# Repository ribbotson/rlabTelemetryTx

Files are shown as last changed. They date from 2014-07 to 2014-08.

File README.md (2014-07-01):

rlabTelemetryTx
===============

rlab Telemetry Transmitter

This repository contains code, hardware information and data relating to the rlab Telemetry Transmittter.

The rlab Telemetry Transmitter is an ATXMega128A4U based development board for High altitude Balloon tracking and telemetry.
The transmitter is a Radiometrix NTX2B 434MHz module and the GPS is the Ublox7q. The board is programmed using Atmel DFU over the
USB .

Software is based around the Atmel Software Framework ASF.

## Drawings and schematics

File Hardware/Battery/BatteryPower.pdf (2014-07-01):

A

A

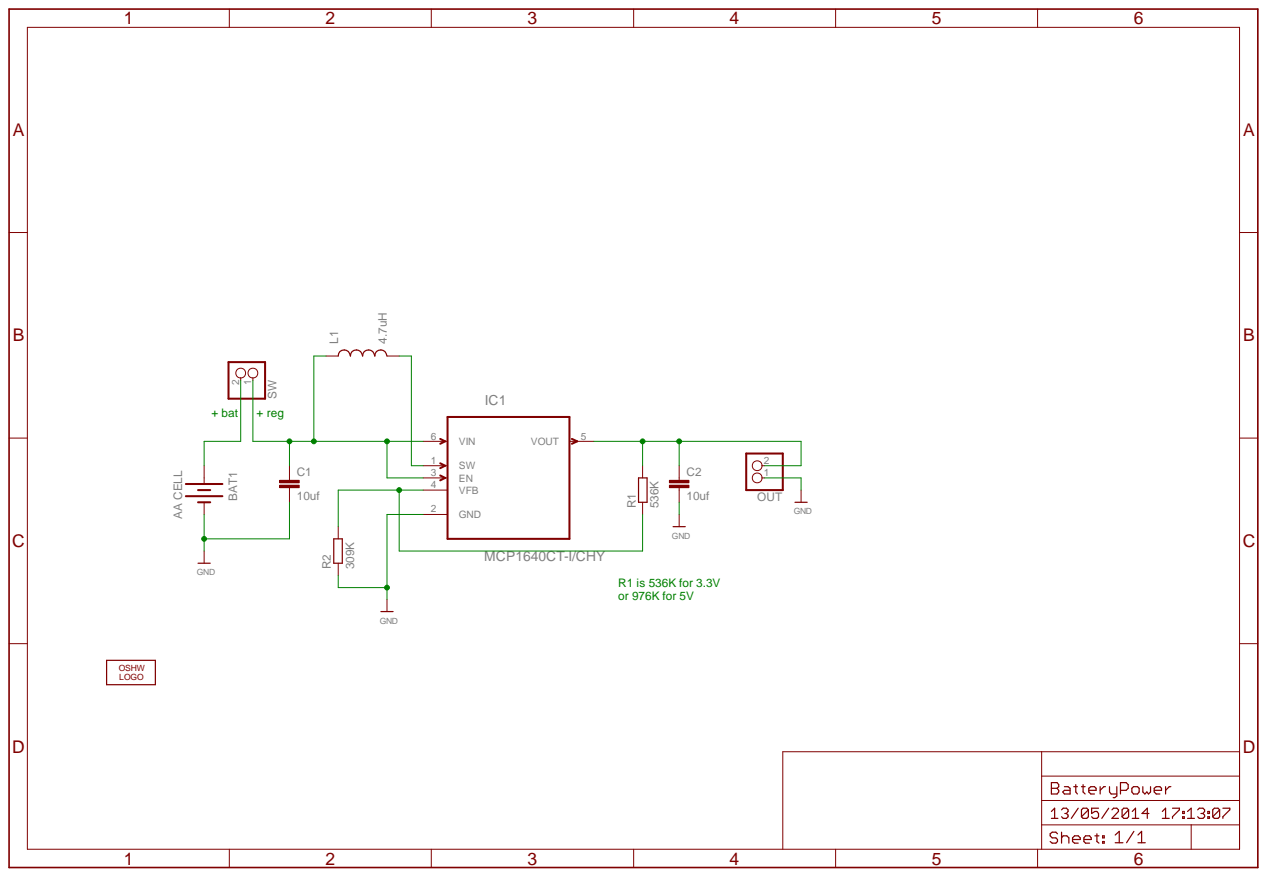
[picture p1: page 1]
AA CELL; GND; MCP1640CT-I/CHY; 4.7uH GND; BAT1; VIN 6; SW 1 EN 3 VFB 4; GND 2; VOUT; OUT; OSHW LOGO; + bat; + reg; R1 is 536K for 3.3V or 976K for 5V

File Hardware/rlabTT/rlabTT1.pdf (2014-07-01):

IC4

A

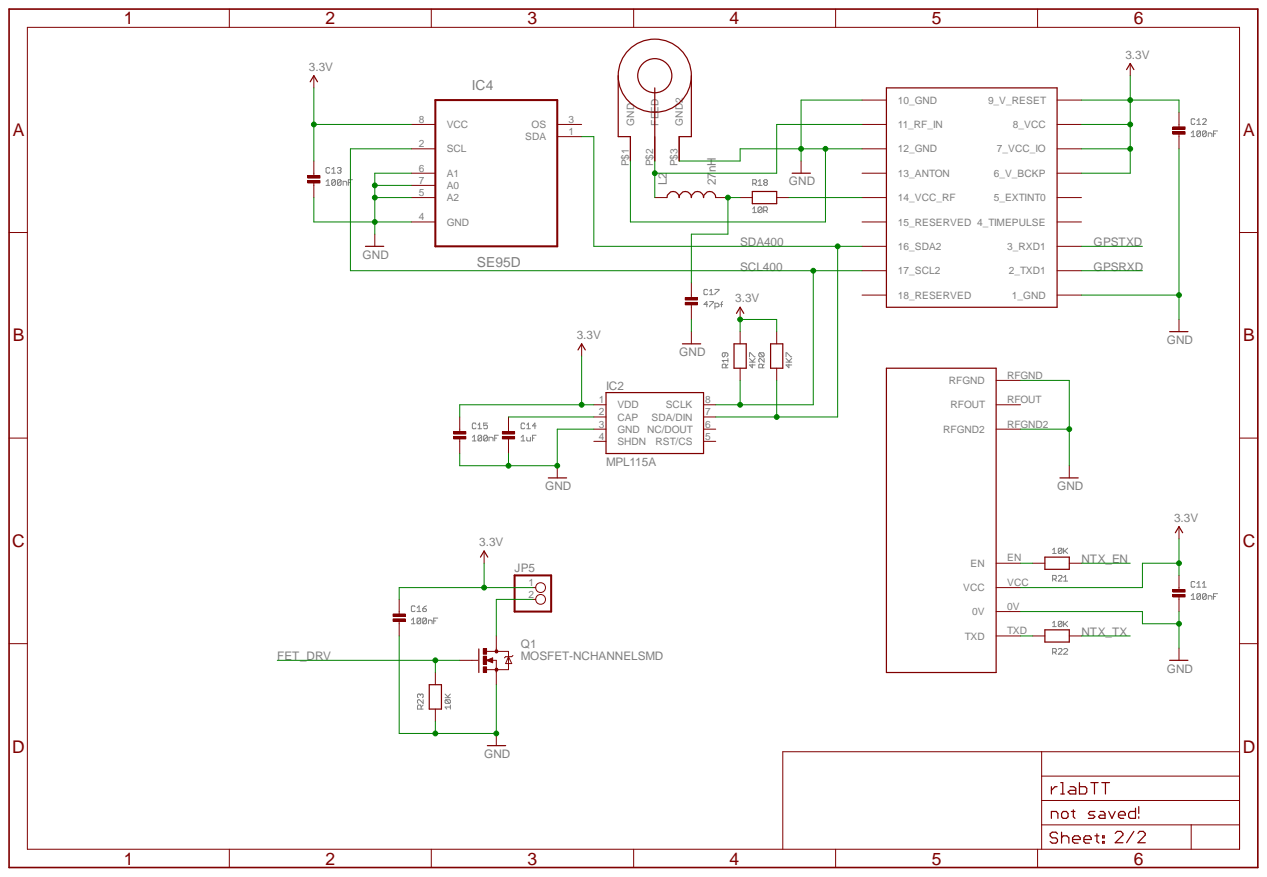
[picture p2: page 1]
GND; MPL115A; MOSFET-NCHANNELSMD; 10_GND; 12_GND; 13_ANTON; 14_VCC_RF; 15_RESERVED; 16_SDA2; 17_SCL2; 18_RESERVED; 9_V_RESET; 8_VCC; 7_VCC_IO; 6_V_BCKP; 5_EXTINT0; 4_TIMEPULSE; 3_RXD1; 2_TXD1; 1_GND; RFGND; RFOUT; VCC; TXD; RFGND2; IC2 VDD 1 CAP 2 GND 3; SHDN 4; RST/CS; 5 NC/DOUT; 6 SDA/DIN; 7 SCLK; FEED P$2; GND P$1; GND2 P$3; VCC 8; SCL 2; GND 4; SDA; GPSRXD; GPSTXD; SCL400; SDA400; FET_DRV; NTX_EN; NTX_TX

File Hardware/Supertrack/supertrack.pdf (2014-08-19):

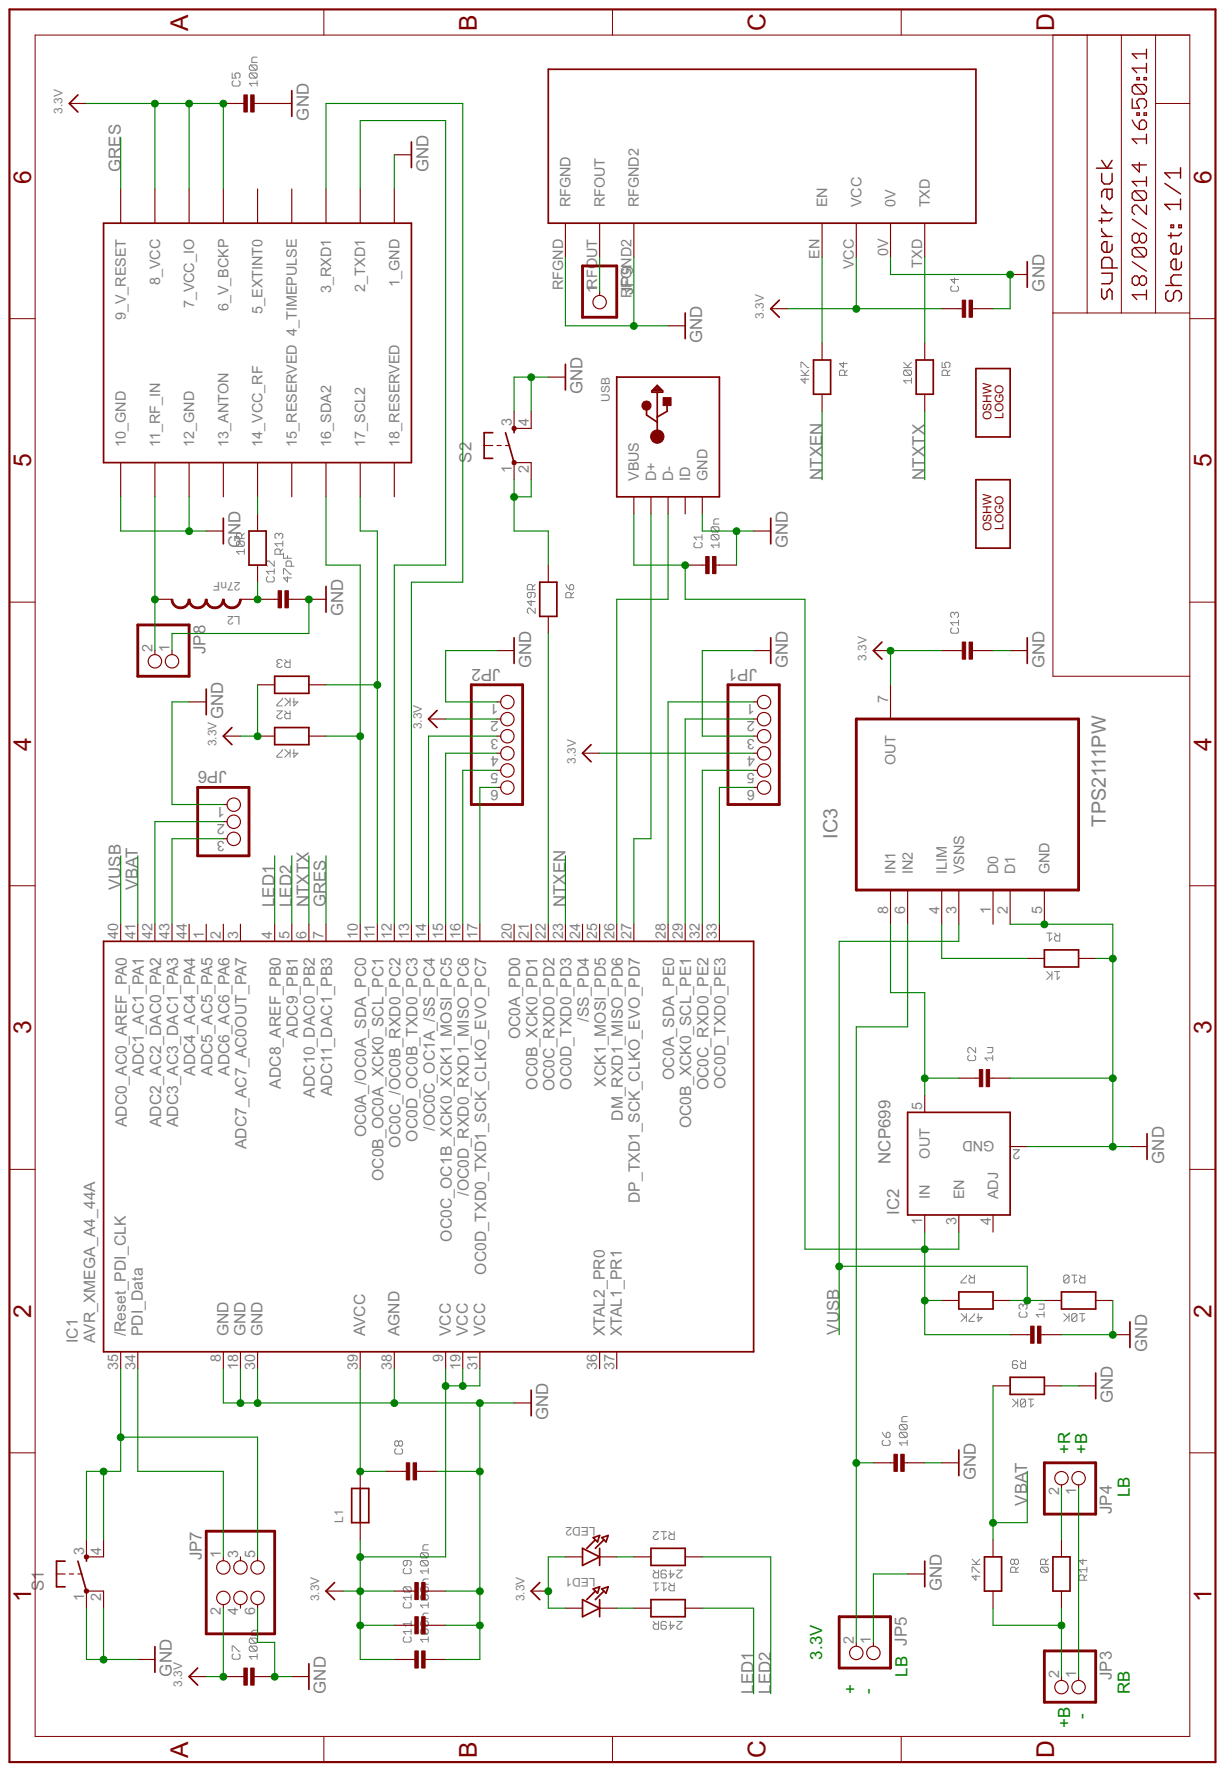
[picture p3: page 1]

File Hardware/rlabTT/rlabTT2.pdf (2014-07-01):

A

A

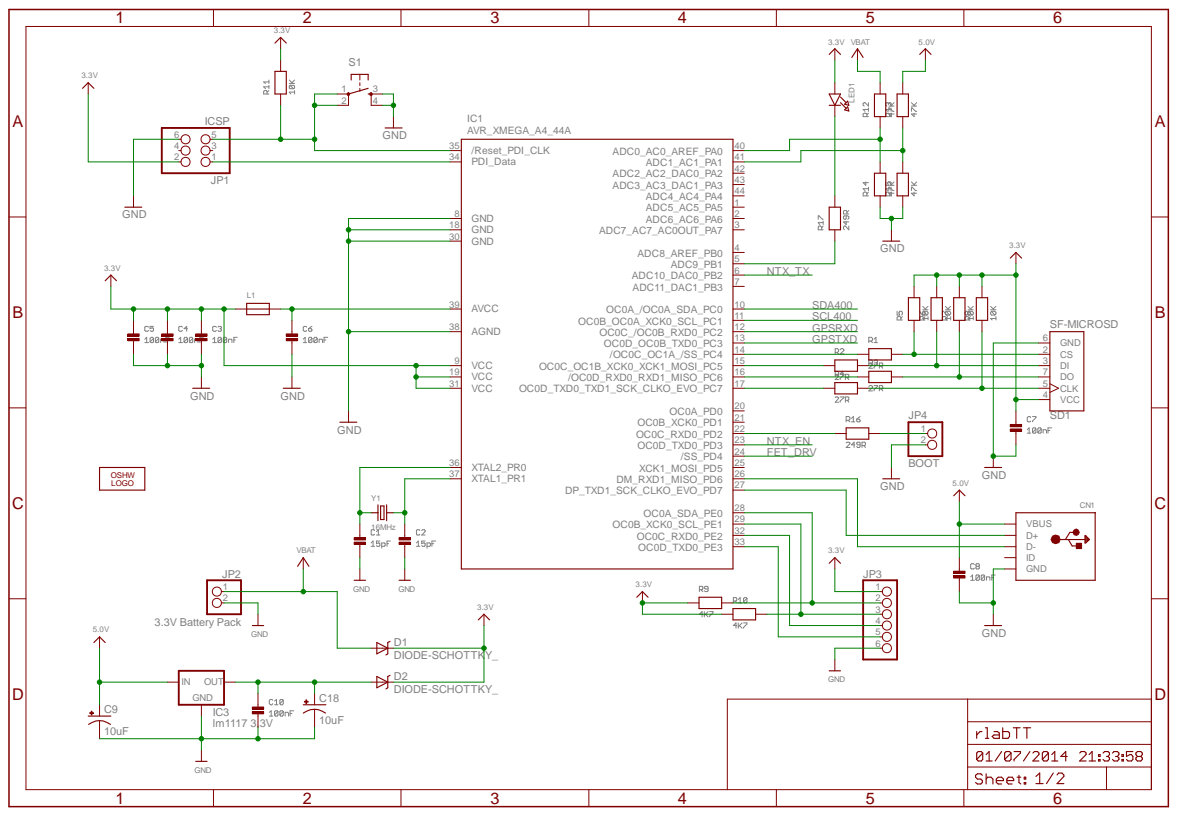
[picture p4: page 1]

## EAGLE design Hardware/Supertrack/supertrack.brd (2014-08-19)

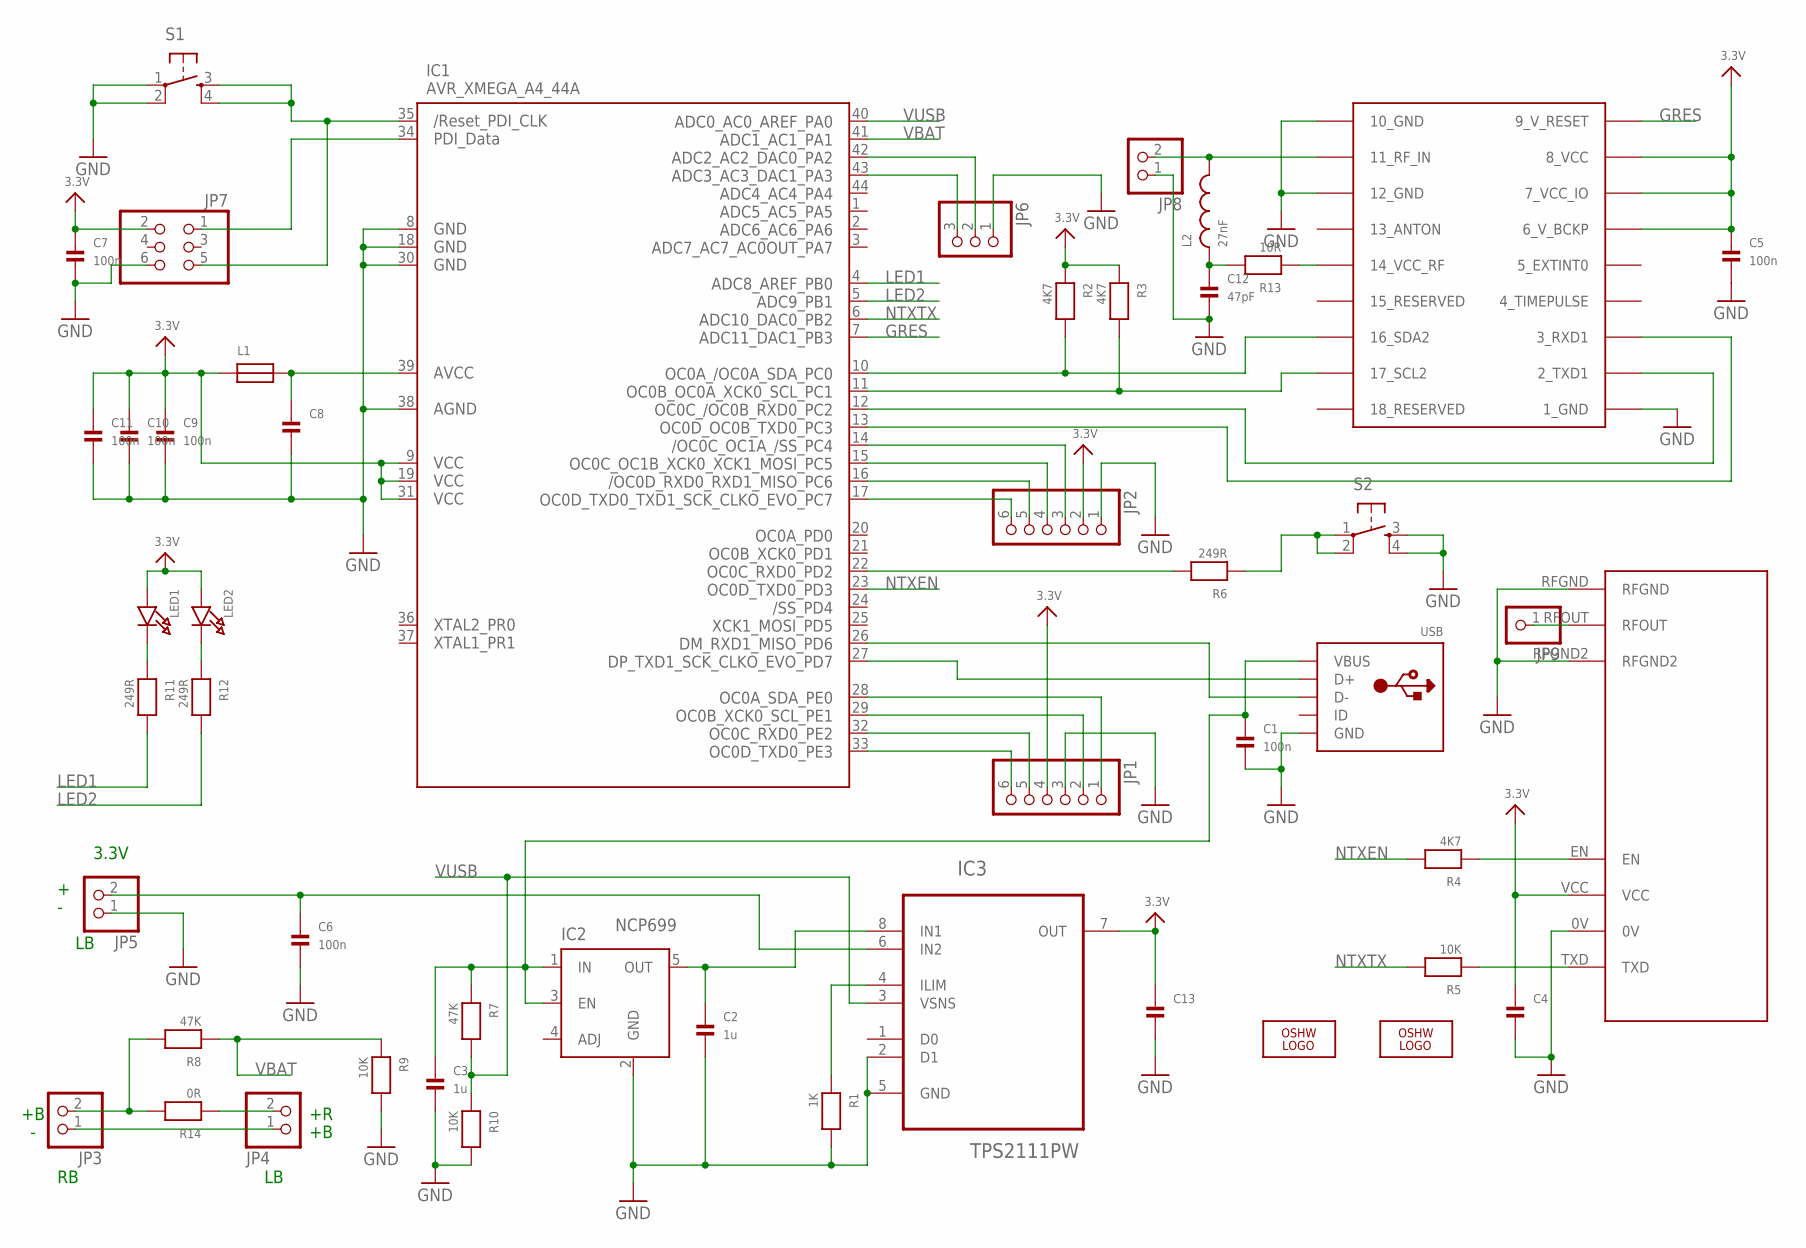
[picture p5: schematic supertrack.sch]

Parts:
C1, C5, C6, C7, C9, C10, C11: 100n; 0603
C2, C3: 1u; 0603
C4, C8, C13: CAP_CERAMIC0603; 0603
C12: 47pF; 0603
IC1: AVR_XMEGA_A4_44A; TQFP44
IC2: NCP699; SOT23-5
IC3: TPS2111PW; SOP65P640X120-8N
JP1, JP2: PINHD-1X6; 1X06
JP3, JP4, JP5: PINHD-1X2; 1X02
JP6: PINHD-1X3; 1X03
JP7: PINHD-2X3; 2X03
JP8: HEADER-1X2ROUND; 1X02_ROUND
JP9: HEADER-1X1ROUND; 1X01_ROUND
L1: FERRITE; 0603
L2: 27nF; 0603
LED1, LED2: LED0603; CHIPLED_0603
LOGO1: OSHW_LOGO_8MILX0150-NT; OSHW_8X150_NOTEXT
LOGO2: OSHW_LOGO_8MILX0100-NT; OSHW_8X100_NOTEXT
R1: 1K; 0603
R2, R3, R4: 4K7; 0603
R5, R9, R10: 10K; 0603
R6, R11, R12: 249R; 0603
R7, R8: 47K; 0603
R13: 10R; 0603
R14: 0R; 0603
S1, S2: TAC_SWITCHSMD; TACTILE_SWITCH_SMD
U$1: NTX2
U$2: UBLOX_MAX
USB: USBMINIB; USB-MINIB

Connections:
3.3V: C4.1, C5.1, C7.1, C9.1, C10.1, C11.1, C13.1, IC1.9 (VCC1), IC1.19 (VCC2), IC1.31 (VCC3), IC3.7 (OUT), JP1.4, JP2.2, JP7.2, L1.1, LED1.A, LED2.A, R2.1, R3.1, U$1.VCC, U$2.6_V_BCKP, U$2.7_VCC_IO, U$2.8_VCC
GND: C1.2, C2.2, C3.2, C4.2, C5.2, C6.2, C7.2, C8.2, C9.2, C10.2, C11.2, C12.2, C13.2, IC1.8 (GND1), IC1.18 (GND2), IC1.30 (GND3), IC1.38 (AGND), IC2.2 (GND), IC3.2 (D1), IC3.5 (GND), JP1.3, JP2.1, JP5.1, JP6.1, JP7.6, JP8.1, R1.2, R9.2, R10.2, S1.1, S1.2, S2.3, S2.4, U$1.0V, U$1.RFGND, U$1.RFGND2, U$2.1_GND, U$2.10_GND, U$2.12_GND, USB.GND
GRES: IC1.7 (PB3), U$2.9_V_RESET
LED1: IC1.4 (PB0), R11.2
LED2: IC1.5 (PB1), R12.2
unnamed: C2.1, IC2.5 (OUT), IC3.8 (IN1)
unnamed: IC1.33 (PE3), JP1.6
unnamed: IC1.32 (PE2), JP1.5
unnamed: C6.1, IC3.6 (IN2), JP5.2
unnamed: R6.1, S2.1, S2.2
unnamed: IC1.26 (PD6), USB.D-
unnamed: IC1.27 (PD7), USB.D+
unnamed: IC1.22 (PD2), R6.2
unnamed: R5.1, U$1.TXD
unnamed: R4.1, U$1.EN
unnamed: JP9.1, U$1.RFOUT
unnamed: C1.1, C3.1, IC2.1 (IN), IC2.3 (EN), R7.1, USB.VBUS
unnamed: IC3.4 (ILIM), R1.1
unnamed: IC1.10 (PC0), R2.2, U$2.16_SDA2
unnamed: IC1.11 (PC1), R3.2, U$2.17_SCL2
unnamed: IC1.12 (PC2), U$2.2_TXD1
unnamed: IC1.13 (PC3), U$2.3_RXD1
unnamed: LED2.C, R12.1
unnamed: LED1.C, R11.1
unnamed: IC1.29 (PE1), JP1.2
unnamed: IC1.28 (PE0), JP1.1
unnamed: IC1.17 (PC7), JP2.6
unnamed: IC1.16 (PC6), JP2.5
unnamed: IC1.15 (PC5), JP2.4
unnamed: IC1.14 (PC4), JP2.3
unnamed: JP3.1, JP4.1
unnamed: JP4.2, R14.1
unnamed: IC1.34 (PDI_DATA), JP7.1
unnamed: IC1.35 (RESET), JP7.5, S1.3, S1.4
unnamed: IC1.42 (PA2), JP6.2
unnamed: IC1.43 (PA3), JP6.3
unnamed: JP8.2, L2.2, U$2.11_RF_IN
unnamed: C12.1, L2.1, R13.2
unnamed: R13.1, U$2.14_VCC_RF
unnamed: C8.1, IC1.39 (AVCC), L1.2
NTXEN: IC1.23 (PD3), R4.2
NTXTX: IC1.6 (PB2), R5.2
VBAT: IC1.41 (PA1), R8.1, R9.1
VIN: JP3.2, R8.2, R14.2
VUSB: IC1.40 (PA0), IC3.3 (VSNS), R7.2, R10.1

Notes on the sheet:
3.3V

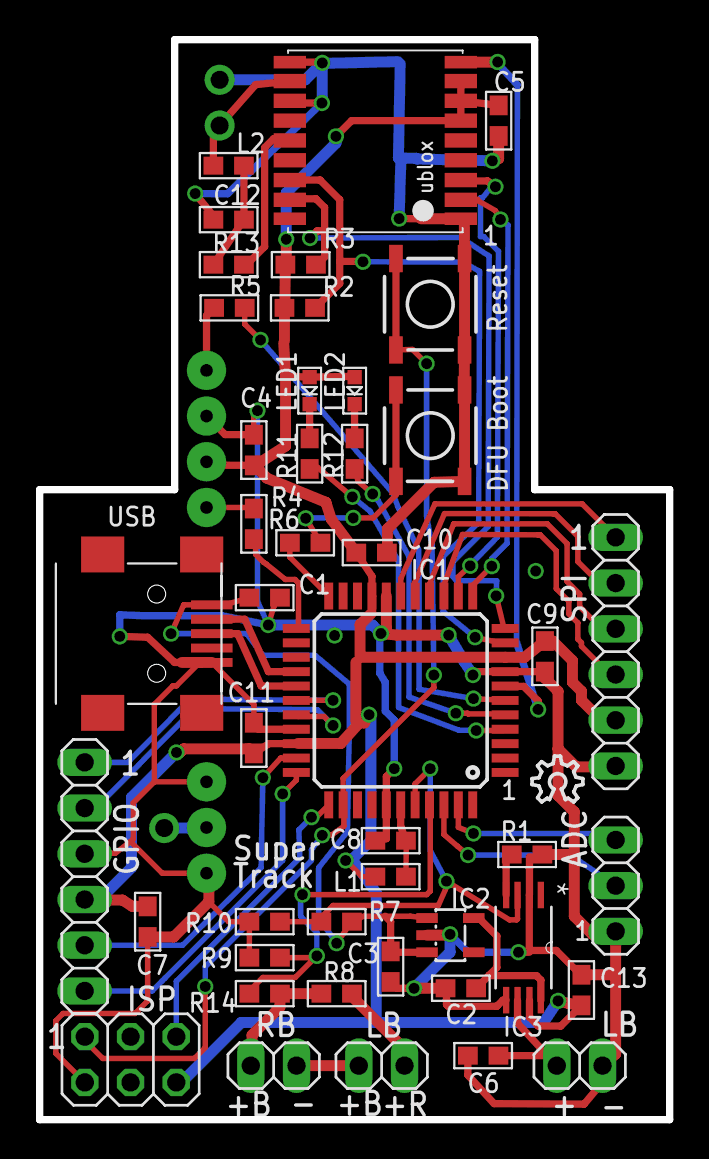
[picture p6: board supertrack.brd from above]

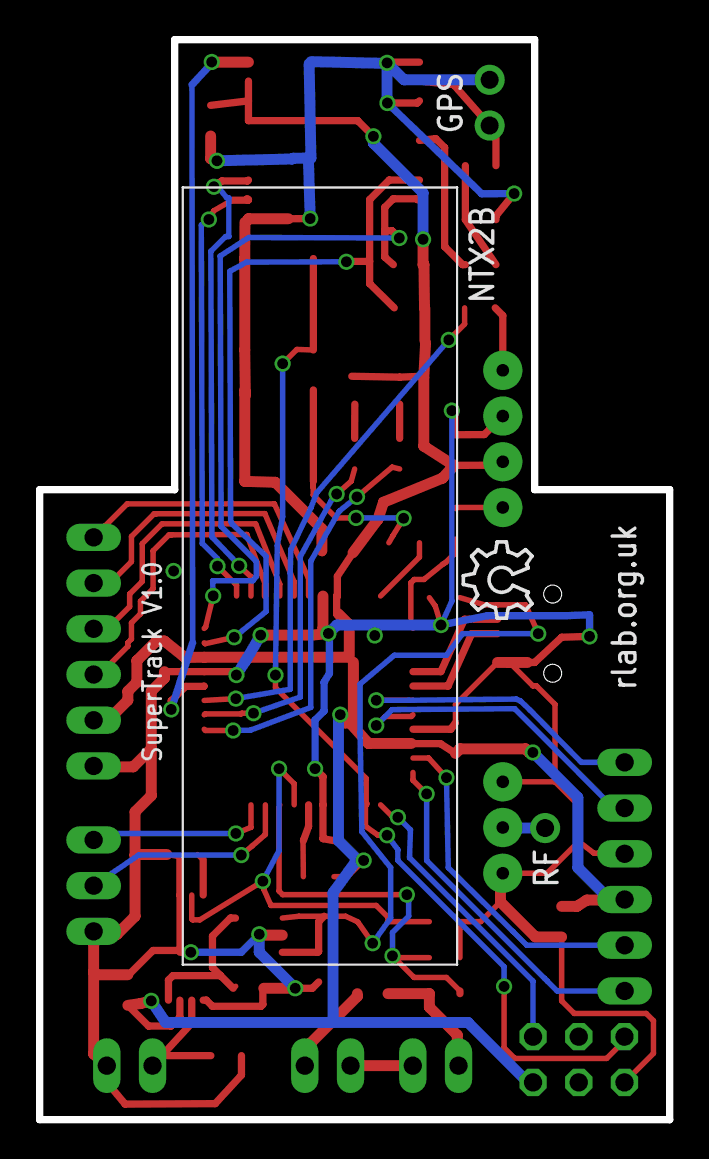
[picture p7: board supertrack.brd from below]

Board: 2 copper layers, 35.0 x 60.0 mm, 50 parts (2 on the bottom side), 45 nets.

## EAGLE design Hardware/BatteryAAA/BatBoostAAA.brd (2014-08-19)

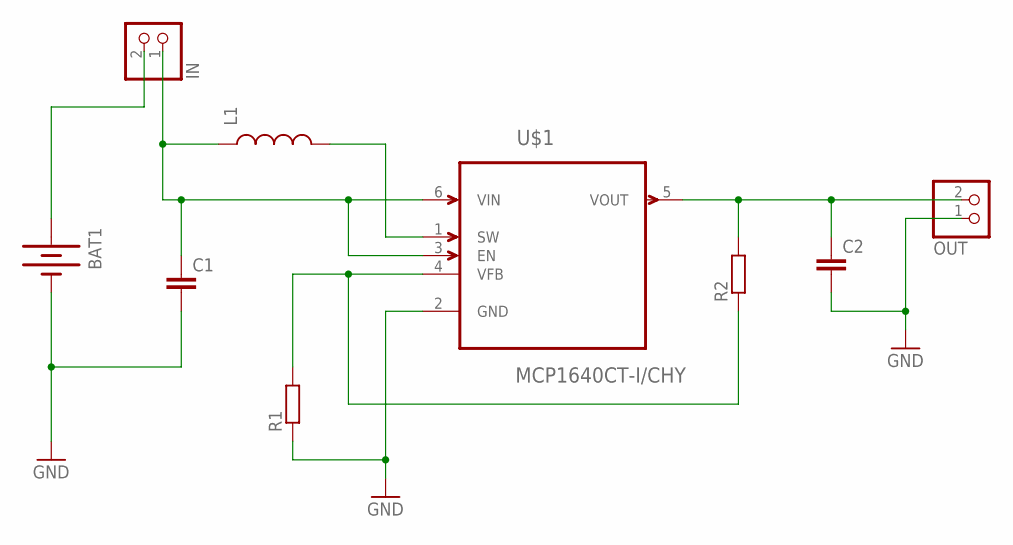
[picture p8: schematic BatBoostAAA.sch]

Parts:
BAT1: BATTERYAAA; BATTERY-AAA
C1, C2: C-EUC0805K; C0805K
IN: PINHD-1X2; 1X02
L1: INDUCTOR1210; LQH32
OUT: PINHD-1X2; 1X02
R1, R2: R-EU_R0603; R0603
U$1: MCP1640CT-I/CHY; SOT95P270X145-6N

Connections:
GND: BAT1.GND@1 (-), C1.2, C2.2, OUT.1, R1.1, U$1.2 (GND)
unnamed: C1.1, IN.1, L1.1, U$1.3 (EN), U$1.6 (VIN)
unnamed: C2.1, OUT.2, R2.2, U$1.5 (VOUT)
unnamed: R1.2, R2.1, U$1.4 (VFB)
unnamed: L1.2, U$1.1 (SW)
unnamed: BAT1.PWR@1 (+), IN.2

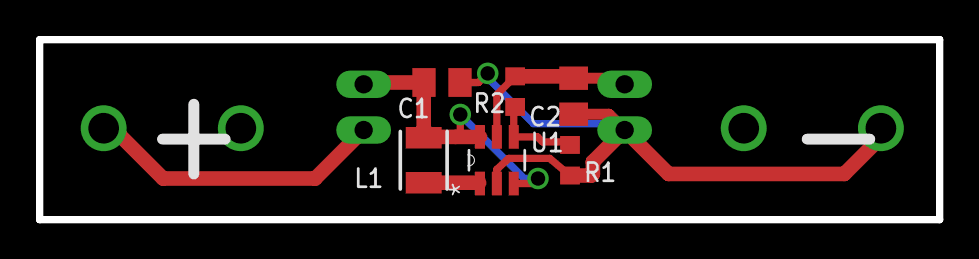
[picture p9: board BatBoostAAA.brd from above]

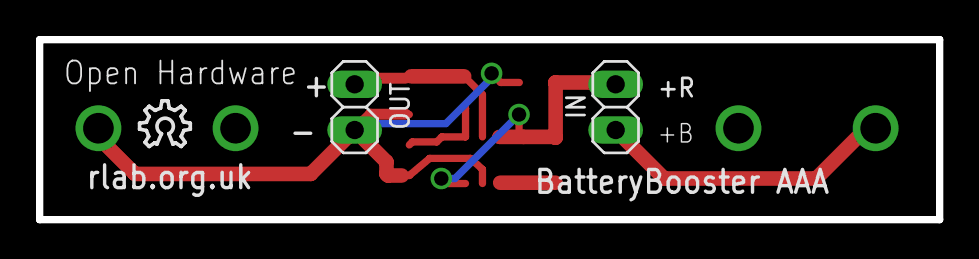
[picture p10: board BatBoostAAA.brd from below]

Board: 2 copper layers, 50.0 x 10.0 mm, 10 parts (3 on the bottom side), 6 nets.

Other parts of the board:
U$2: OSHW_8X100_NOTEXT

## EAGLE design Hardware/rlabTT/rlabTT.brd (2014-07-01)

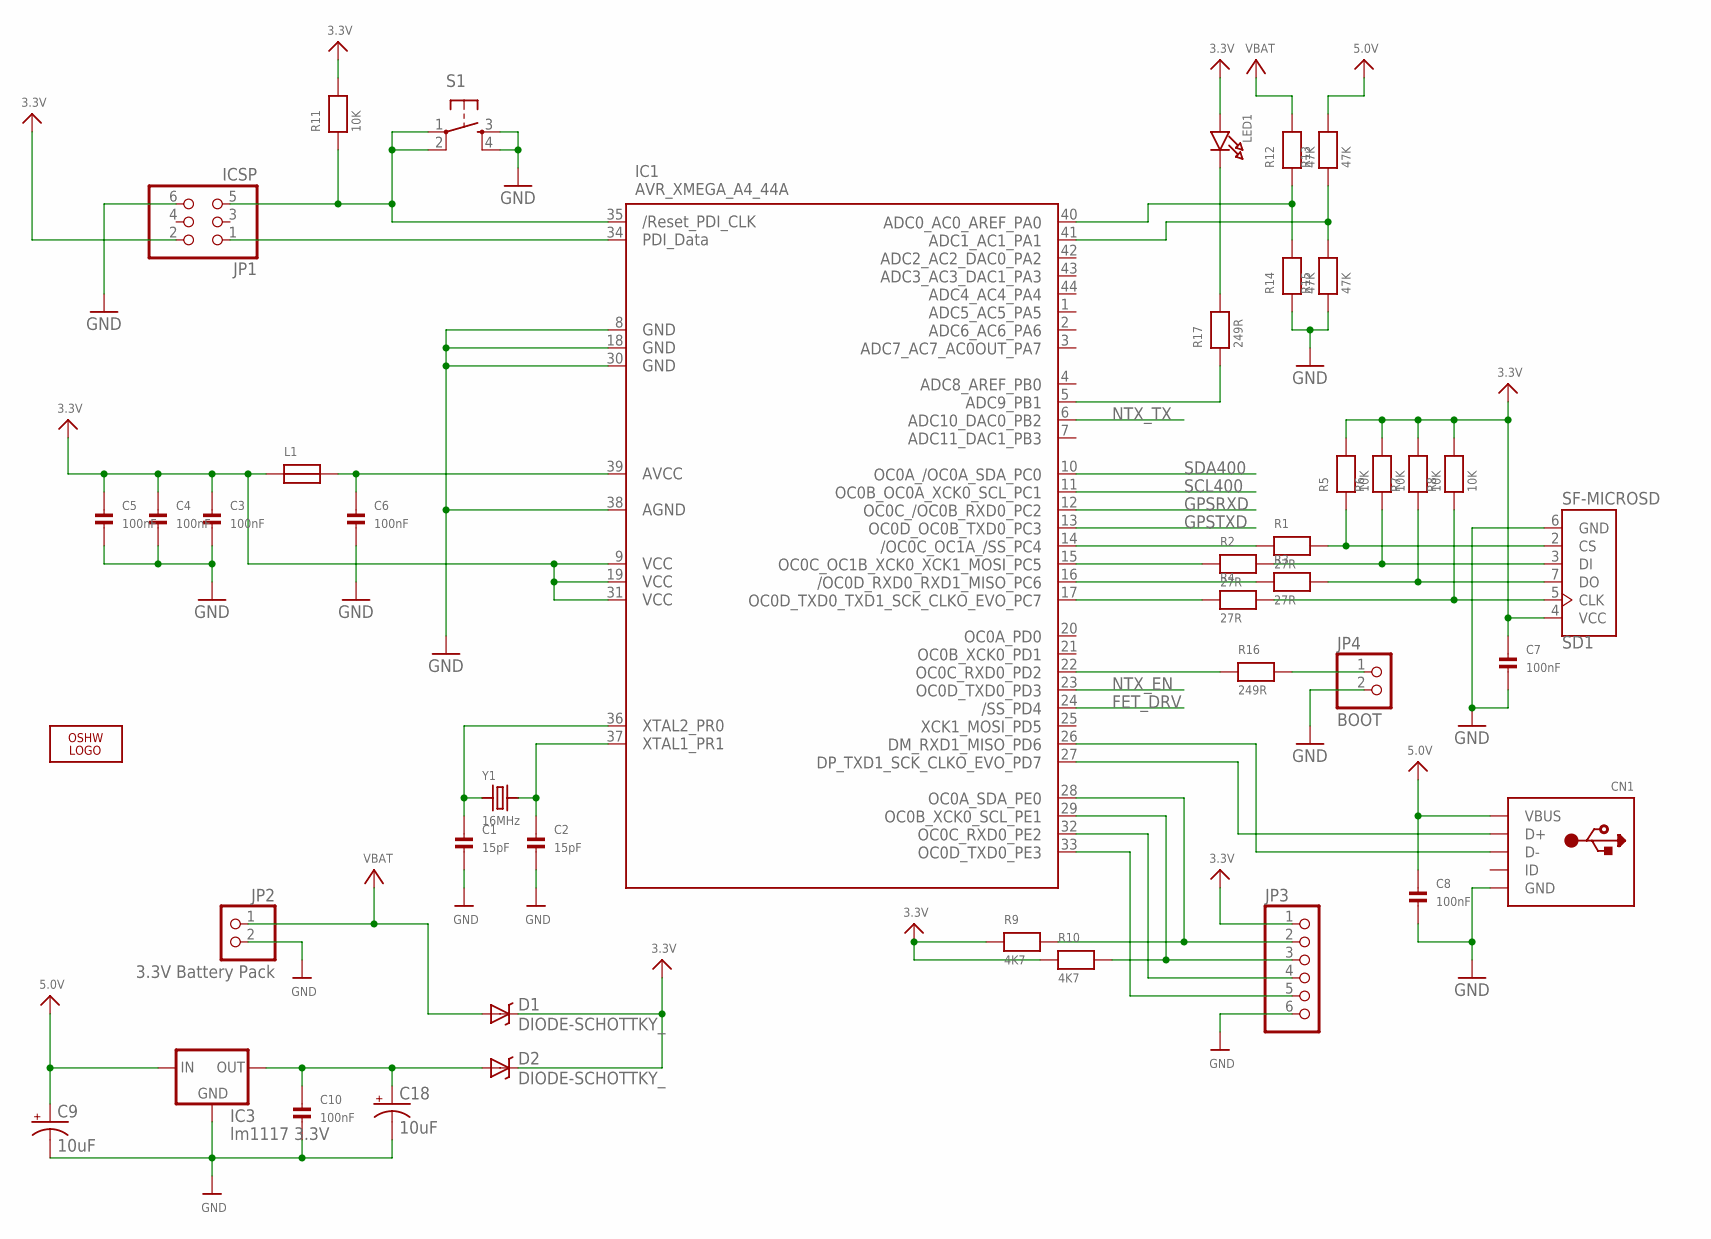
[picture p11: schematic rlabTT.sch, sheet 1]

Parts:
C1, C2: 15pF; 0603
C3, C4, C5, C6, C7, C8, C10: 100nF; 0603
C9, C18: 10uF; EIA3528
CN1: USBMINIB; USB-MINIB
D1, D2: DIODE-SCHOTTKY_; SMA-DIODE
IC1: AVR_XMEGA_A4_44A; TQFP44
IC3: lm1117 3.3V; SOT223
JP1: ICSP; 2X03/90
JP2: 3.3V Battery Pack; 1X02/90
JP3: PINHD-1X6/90; 1X06/90
JP4: BOOT; 1X02/90
L1: FERRITE; 0603
LED1: LED0603; CHIPLED_0603
LOGO1: OSHW_LOGO_8MILX0150-NT; OSHW_8X150_NOTEXT
R1, R2, R3, R4: 27R; 0603
R5, R6, R7, R8, R11: 10K; 0603
R9, R10: 4K7; 0603
R12, R13, R14, R15: 47K; 0603
R16, R17: 249R; 0603
S1: TAC_SWITCHSMD; TACTILE_SWITCH_SMD
SD1: SF-MICROSD; MICROSD
Y1: 16MHz; CRYSTAL_3.2X2.5

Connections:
3.3V: C3.1, C4.1, C5.1, C7.1, D1.C, D2.C, IC1.9 (VCC1), IC1.19 (VCC2), IC1.31 (VCC3), JP1.2, JP3.1, L1.1, LED1.A, R5.2, R6.2, R7.2, R8.2, R9.1, R10.1, R11.2, SD1.4 (VCC); also elsewhere on the board
5.0V: C8.1, C9.A (+), CN1.VBUS, IC3.3 (IN), R13.2
FET_DRV: IC1.24 (PD4); also elsewhere on the board
GND: C1.2, C2.2, C3.2, C4.2, C5.2, C6.2, C7.2, C8.2, C9.C (-), C10.2, C18.C (-), CN1.GND, IC1.8 (GND1), IC1.18 (GND2), IC1.30 (GND3), IC1.38 (AGND), IC3.1 (GND), JP1.6, JP2.2, JP3.6, JP4.2, R14.1, R15.1, S1.3, S1.4, SD1.6 (GND); also elsewhere on the board
GPSRXD: IC1.12 (PC2); also elsewhere on the board
GPSTXD: IC1.13 (PC3); also elsewhere on the board
unnamed: IC1.40 (PA0), R12.1, R14.2
unnamed: IC1.22 (PD2), R16.1
unnamed: IC1.41 (PA1), R13.1, R15.2
unnamed: JP4.1, R16.2
unnamed: IC1.5 (PB1), R17.1
unnamed: LED1.C, R17.2
unnamed: C2.1, IC1.37 (PR1), Y1.2
unnamed: C1.1, IC1.36 (PR0), Y1.1
unnamed: C6.1, IC1.39 (AVCC), L1.2
unnamed: IC1.14 (PC4), R1.1
unnamed: CN1.D+, IC1.27 (PD7)
unnamed: CN1.D-, IC1.26 (PD6)
unnamed: IC1.15 (PC5), R2.1
unnamed: IC1.16 (PC6), R3.1
unnamed: IC1.17 (PC7), R4.1
unnamed: R1.2, R5.1, SD1.2 (CS)
unnamed: R2.2, R6.1, SD1.3 (DI)
unnamed: R3.2, R7.1, SD1.7 (DO)
unnamed: IC1.35 (RESET), JP1.5, R11.1, S1.1, S1.2
unnamed: IC1.34 (PDI_DATA), JP1.1
unnamed: C10.1, C18.A (+), D2.A, IC3.2 (OUT)
unnamed: IC1.28 (PE0), JP3.2, R9.2
unnamed: IC1.29 (PE1), JP3.3, R10.2
unnamed: IC1.32 (PE2), JP3.4
unnamed: IC1.33 (PE3), JP3.5
NTX_EN: IC1.23 (PD3); also elsewhere on the board
NTX_TX: IC1.6 (PB2); also elsewhere on the board
SCL400: IC1.11 (PC1); also elsewhere on the board
SD1: R4.2, R8.1, SD1.5 (CLK)
SDA400: IC1.10 (PC0); also elsewhere on the board
VBAT: D1.A, JP2.1, R12.2

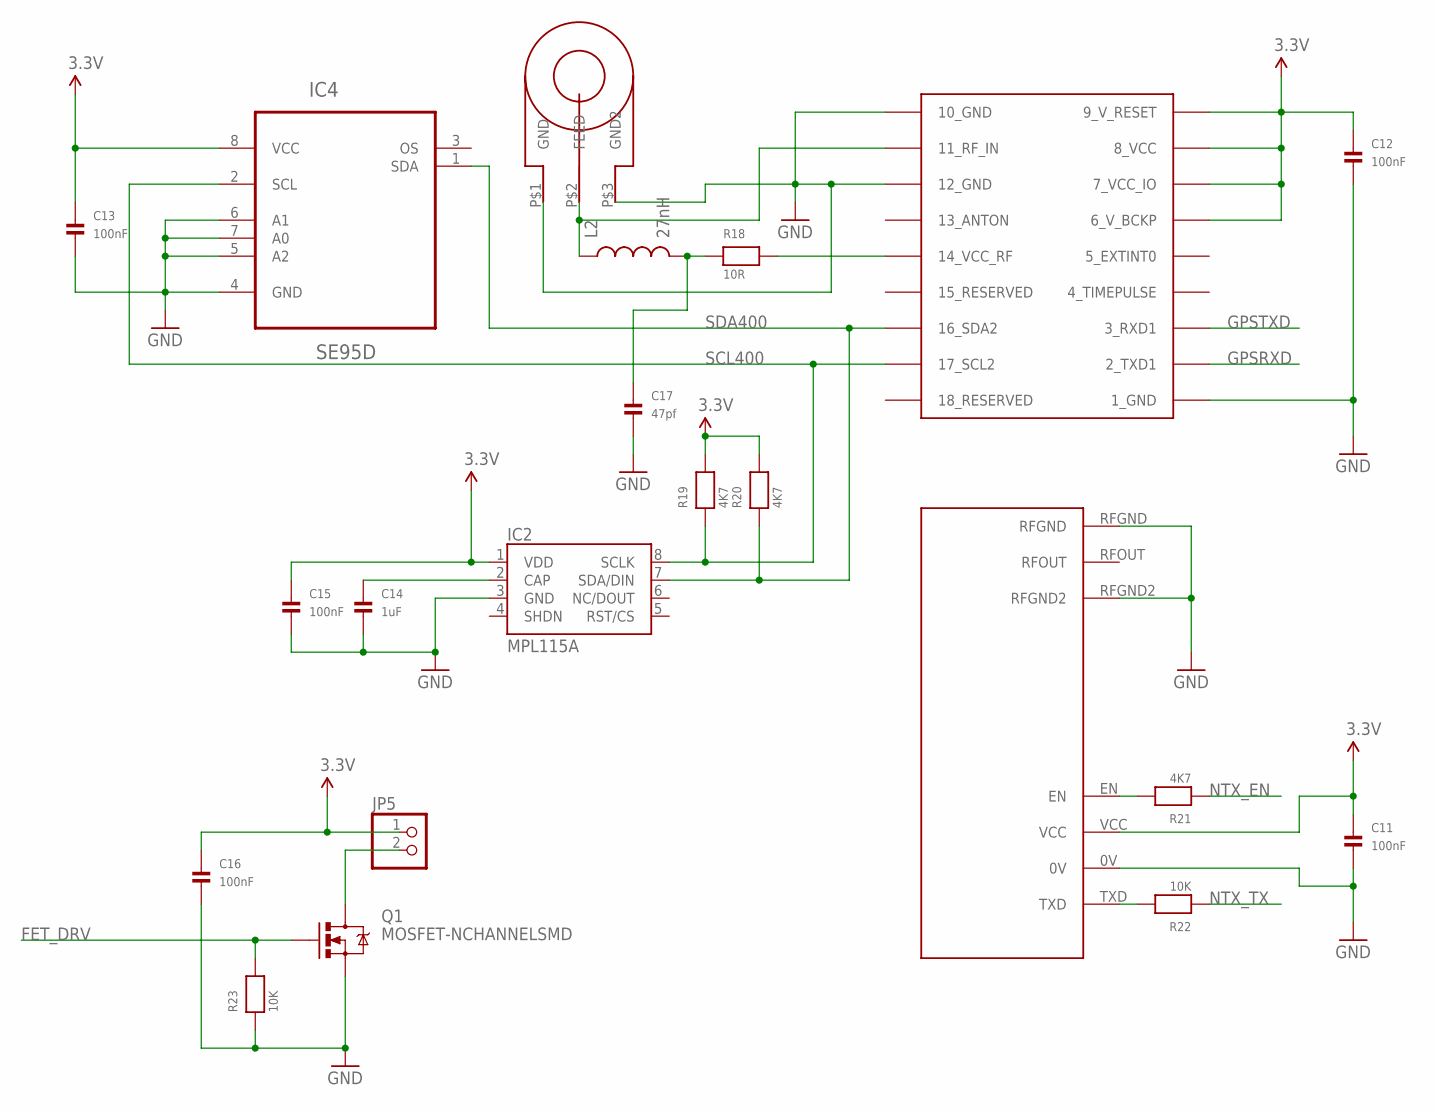
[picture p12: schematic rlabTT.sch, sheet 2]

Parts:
C11, C12, C13, C15, C16: 100nF; 0603
C14: 1uF; 0603
C17: 47pf; 0603
IC2: MPL115A; LGA8
IC4: SE95D; SOIC127P600X175-8N
JP5: PINHD-1X2/90; 1X02/90
L2: 27nH; 0603
Q1: MOSFET-NCHANNELSMD; SOT23-3
R18: 10R; 0603
R19, R20, R21: 4K7; 0603
R22, R23: 10K; 0603
U1: UBLOX_MAX
U2: NTX2
U3: SARANTEL-SL1250

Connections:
3.3V: C11.1, C12.1, C13.1, C15.1, C16.1, IC2.1 (VDD), IC4.8 (VCC), JP5.1, R19.2, R20.2, U1.6_V_BCKP, U1.7_VCC_IO, U1.8_VCC, U1.9_V_RESET, U2.VCC; also elsewhere on the board
FET_DRV: Q1.1 (G), R23.2; also elsewhere on the board
GND: C11.2, C12.2, C13.2, C14.2, C15.2, C16.2, C17.2, IC2.3 (GND), IC4.4 (GND), IC4.5 (A2), IC4.6 (A1), IC4.7 (A0), Q1.2 (S), R23.1, U1.1_GND, U1.10_GND, U1.12_GND, U2.0V, U2.RFGND, U2.RFGND2, U3.P$1 (GND), U3.P$3 (GND2); also elsewhere on the board
GPSRXD: U1.2_TXD1; also elsewhere on the board
GPSTXD: U1.3_RXD1; also elsewhere on the board
unnamed: L2.1, U1.11_RF_IN, U3.P$2 (FEED)
unnamed: R21.2, U2.EN
unnamed: R18.2, U1.14_VCC_RF
unnamed: C17.1, L2.2, R18.1
unnamed: R22.2, U2.TXD
unnamed: JP5.2, Q1.3 (D)
unnamed: C14.1, IC2.2 (CAP)
NTX_EN: R21.1; also elsewhere on the board
NTX_TX: R22.1; also elsewhere on the board
SCL400: IC2.8 (SCLK), IC4.2 (SCL), R19.1, U1.17_SCL2; also elsewhere on the board
SDA400: IC2.7 (SDA/DIN), IC4.1 (SDA), R20.1, U1.16_SDA2; also elsewhere on the board

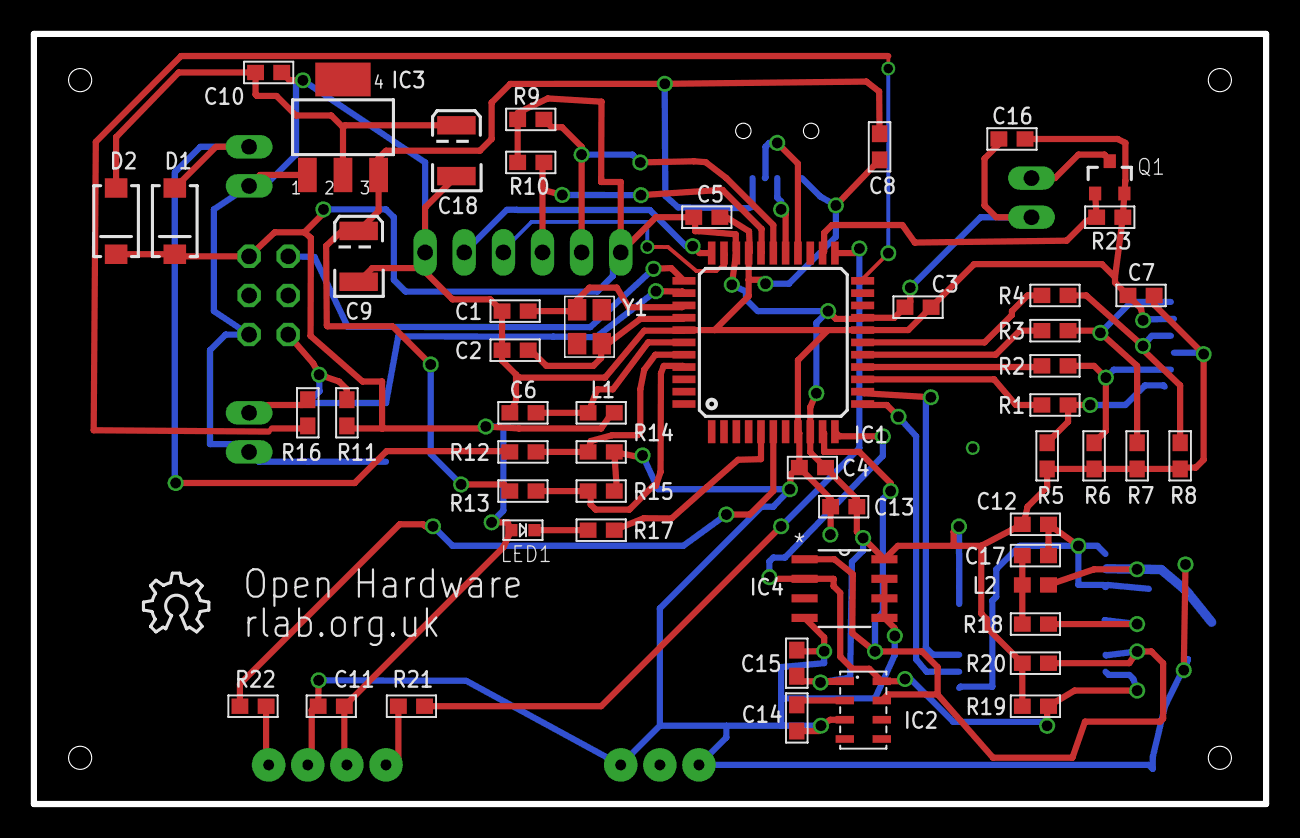
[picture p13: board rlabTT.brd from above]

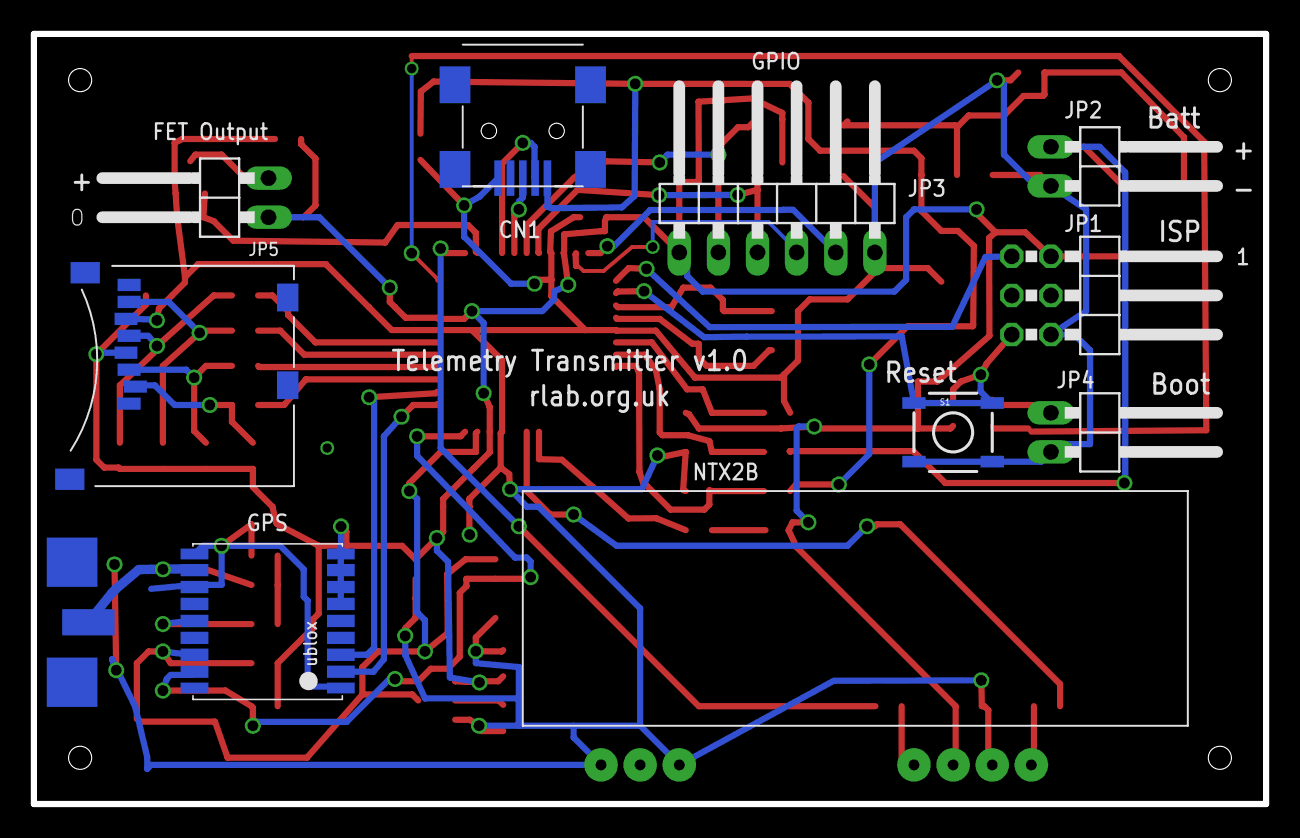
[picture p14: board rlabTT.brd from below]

Board: 2 copper layers, 80.0 x 50.0 mm, 64 parts (11 on the bottom side), 44 nets.

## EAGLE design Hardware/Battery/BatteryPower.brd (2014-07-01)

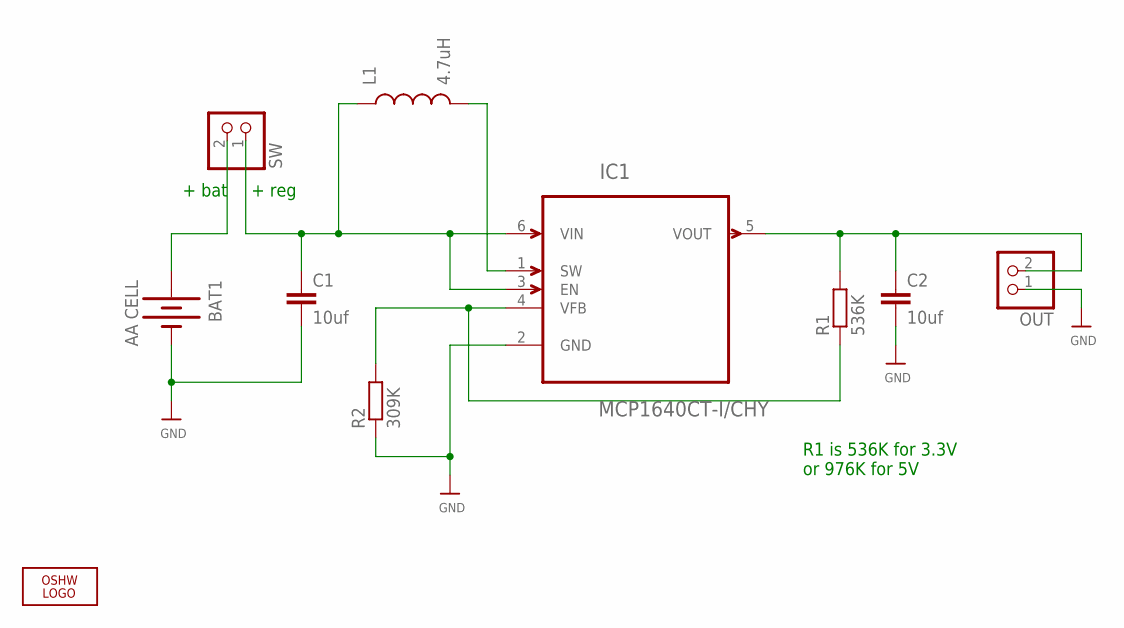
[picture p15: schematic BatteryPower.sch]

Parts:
BAT1: AA CELL; BATTERY-AA
C1, C2: 10uf; C0805
IC1: MCP1640CT-I/CHY; SOT95P270X145-6N
L1: 4.7uH; CR75
LOGO1: OSHW_LOGO_8MILX0150-NT; OSHW_8X150_NOTEXT
OUT: PINHD-1X2/90; 1X02/90
R1: 536K; R0603
R2: 309K; R0603
SW: PINHD-1X2/90; 1X02/90

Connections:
GND: BAT1.GND@1 (-), C1.2, C2.2, IC1.2 (GND), OUT.1, R2.1
unnamed: C1.1, IC1.3 (EN), IC1.6 (VIN), L1.P$1 (1), SW.1
unnamed: IC1.1 (SW), L1.P$2 (2)
unnamed: IC1.4 (VFB), R1.1, R2.2
unnamed: C2.1, IC1.5 (VOUT), OUT.2, R1.2
unnamed: BAT1.PWR@1 (+), SW.2

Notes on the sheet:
+ bat
+ reg
R1 is 536K for 3.3V or 976K for 5V

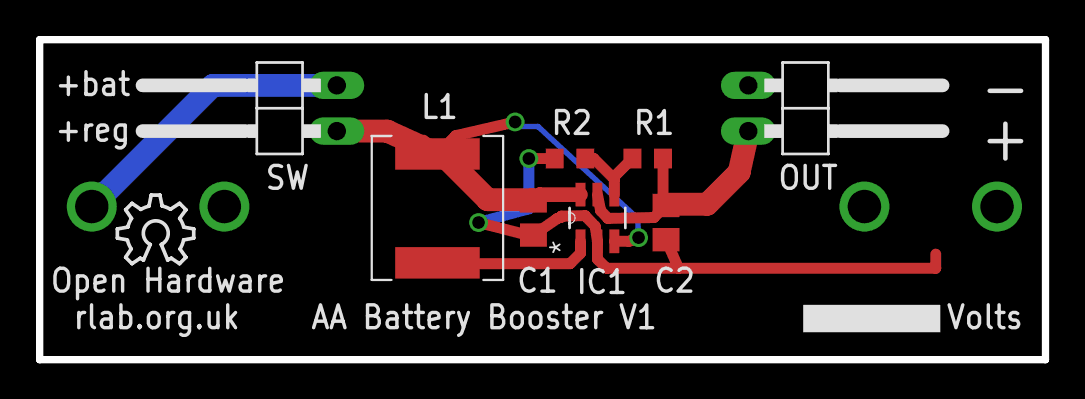
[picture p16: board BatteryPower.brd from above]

Board: 2 copper layers, 55.9 x 17.8 mm, 10 parts (1 on the bottom side), 6 nets.

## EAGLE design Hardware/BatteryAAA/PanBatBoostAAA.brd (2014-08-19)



Board: 2 copper layers, 50.0 x 50.0 mm, 50 parts (15 on the bottom side), 30 nets.

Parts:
BAT1, BAT2, BAT3, BAT4, BAT5: BATTERY-AAA
C1, C2, C3, C4, C5, C6, C7, C8, C9, C10: C0805K
IN, IN1, IN2, IN3, IN4: 1X02
L1, L2, L3, L4, L5: LQH32
OUT, OUT1, OUT2, OUT3, OUT4: 1X02
R1, R2, R3, R4, R5, R6, R7, R8, R9, R10: R0603
U$1, U$3, U$5, U$7, U$9: MCP1640CT-I/CHY; SOT95P270X145-6N
U$2, U$4, U$6, U$8, U$10: OSHW_8X100_NOTEXT

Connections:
GND: BAT1.GND@1, C1.2, C2.2, OUT.1, R1.1, U$1.2
GND1: BAT2.GND@1, C3.2, C4.2, OUT1.1, R3.1, U$3.2
GND2: BAT3.GND@1, C5.2, C6.2, OUT2.1, R5.1, U$5.2
GND3: BAT4.GND@1, C7.2, C8.2, OUT3.1, R7.1, U$7.2
GND4: BAT5.GND@1, C9.2, C10.2, OUT4.1, R9.1, U$9.2
unnamed: C1.1, IN.1, L1.1, U$1.3, U$1.6
unnamed: C2.1, OUT.2, R2.2, U$1.5
unnamed: R1.2, R2.1, U$1.4
unnamed: L1.2, U$1.1
unnamed: BAT1.PWR@1, IN.2
unnamed: C4.1, OUT1.2, R4.2, U$3.5
unnamed: R3.2, R4.1, U$3.4
unnamed: BAT2.PWR@1, IN1.2
unnamed: C3.1, IN1.1, L2.1, U$3.3, U$3.6
unnamed: L2.2, U$3.1
unnamed: C6.1, OUT2.2, R6.2, U$5.5
unnamed: R5.2, R6.1, U$5.4
unnamed: BAT3.PWR@1, IN2.2
unnamed: C5.1, IN2.1, L3.1, U$5.3, U$5.6
unnamed: L3.2, U$5.1
unnamed: C8.1, OUT3.2, R8.2, U$7.5
unnamed: R7.2, R8.1, U$7.4
unnamed: BAT4.PWR@1, IN3.2
unnamed: C7.1, IN3.1, L4.1, U$7.3, U$7.6
unnamed: L4.2, U$7.1
unnamed: C10.1, OUT4.2, R10.2, U$9.5
unnamed: R9.2, R10.1, U$9.4
unnamed: BAT5.PWR@1, IN4.2
unnamed: C9.1, IN4.1, L5.1, U$9.3, U$9.6
unnamed: L5.2, U$9.1

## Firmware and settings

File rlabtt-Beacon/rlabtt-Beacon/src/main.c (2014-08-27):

/*____________________________________________________________________________*/
/*
 * File: main.c
 *
 * Created: 07/06/2014 16:01:06
 * Revised  14/07/2014 16:55
 * Author: Richard Ibbotson
 * Compiler:    GNU-AVR-GCC
 * Project:  rlab Telemetry Transmitter 
 */
/*____________________________________________________________________________*/
/*
 * 
 *  This source module implements the main functions of the rlab Telemetry
 *  Transmitter
 *
 *
*/
/*____________________________________________________________________________*/
/*
 * Copyright, License and Attribution:
 *
 
 *
 * Copyright (c) 2014 Richard Ibbotson (richard.ibbotson@btinternet.com)
 *
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
 * You should have received a copy of the GNU General Public License
 * along with this program.  If not, see <http://www.gnu.org/licenses/>.
 */
/*____________________________________________________________________________*/


#include "asf.h"
#include "string.h"  	// String function definitions
#include "stdio.h"
#include "avr/pgmspace.h"
#include "main.h"
#include "conf_usb.h"
#include "cmnd.h"
#include "sensor.h"
#include "comms.h"
#include "timer.h"
#include "nvconfig.h"

// Global Data to describe the current firmware build
int build_major = 0;
int build_minor = 1;
int build_release = 0;
char * build_date =  (char *) __DATE__ ;

// mapping of files for fprintf
FILE usbout = FDEV_SETUP_STREAM(comms_usb_putchar, NULL,_FDEV_SETUP_WRITE);
FILE extout =FDEV_SETUP_STREAM(ext_ser_putchar, NULL,_FDEV_SETUP_WRITE);
FILE ntx2bout =FDEV_SETUP_STREAM(ntx2b_ser_putchar, NULL,_FDEV_SETUP_WRITE);

// external Status Variables

extern char transmit_state;
extern char power_status;
// Global configuration
struct MAGIC magic = {.magic_number= EEPROM_MAGIC_NUMBER, .config_version = EEPROM_CONFIG_VERSION};
	
struct CONFIG config = {.uart_on_startup = START_UART_AUTO,
						.beacon_repeat_time = 10,
						.payload_id = "rlabtt",
						.modulation_mode = RTTY300,
						.tx_channel = 1,
						.tx_trim = 0x40,
						.cutdown_altitude = 10000.0 };

// String to be sent as beacon and its length
char		beacon_string[100];
unsigned char	beacon_length;

char serial_port = SERIAL_NONE;

// External Task request flags
extern volatile bool    b500msecTaskReq;
extern volatile bool	 bBeaconTaskReq;


/*! \brief Main function. Execution starts here.
 */
int main(void)
{
		
	irq_initialize_vectors();
	cpu_irq_enable();
	
	
	pmic_init();

	// Initialize the sleep manager
	sleepmgr_init();
	
	
	
	sysclk_init();
	
	// set the board to an initial safe state
	board_init();
	
	// get the configuration from eeprom if there else write it
	
	get_nvmagic(&magic); // get magic number structure from EEPROM
	if (magic.magic_number == EEPROM_MAGIC_NUMBER && magic.config_version == EEPROM_CONFIG_VERSION)
	{
		get_nvconfig(&config);
	}
	else
	{
		set_nvmagic(&magic);
		set_nvconfig(&config);
	}
	

	//Initialise the delay system
	delay_init(sysclk_get_cpu_hz())
	
	// default led to off
	LED_Off(LED0_GPIO);
	
	// Start the ADC for power monitoring
	adc_enable(&MY_ADC);
	
	// Initialise GPS and I2C devices
	sensor_init();
	
	// Start all the comms ports
	comms_init();
	
	
	// find out source of power
	check_power_source();
	
	if(config.uart_on_startup == START_UART_USB)
	{
		if(power_status == POWER_USB || power_status == POWER_BOTH)
		{
			// Start USB stack
			udc_start(); // should check if really started
			serial_port = SERIAL_USB;
			// map stdout
			stdout = &usbout;
		}
	}
	
	else if(config.uart_on_startup == START_UART_AUTO)
	{
		if(power_status == POWER_USB || power_status == POWER_BOTH)
		{
			// Start USB stack
			udc_start();
			serial_port = SERIAL_USB;
			// map stdout
			stdout = &usbout;
		}
		else
		{
			serial_port = SERIAL_EXT;
			// map stdout
			stdout = &extout;
			
		}
	}
	
	else if(config.uart_on_startup == START_UART_EXT)
	{
		serial_port = SERIAL_EXT;
		// map stdout
		stdout = &extout;
	}		
	
	
	
	
	// for testing startup
		
	LED_On(LED0_GPIO);
	
	
	

	
	
	
	
	
	// start the timers
	timer_init();
	
	// The main loop 
	
	while (true) {
		if(comms_cdcgotchar()){
			while(udi_cdc_is_rx_ready()){
				 hci_process_input( udi_cdc_getc());
				 
			}				 
			comms_cdc_clr_gotchar();
		}
		if(b500msecTaskReq)
		{
			b500msecTaskReq = false;
			LED_Toggle(LED0_GPIO);
			check_power_source();		
		}
		
		if(bBeaconTaskReq)
		{
			bBeaconTaskReq = false;
			if(transmit_state == TRANSMIT_BEACON)
			{
				if(!ntx2b_mod_busy())
				{
					
					 BuildSentence(beacon_string);
					 printf("Beacon String: %s", beacon_string); 
					 ntx2b_mod_transmit();
				}
				
			}
		}
		get_gps_data();
		sleepmgr_enter_sleep();
	}
}








void BuildSentence(char *beacon_string)
{
	int Count, i, j;
	unsigned int myCRC;
	char TimeBuffer[10];
	static unsigned long SentenceCounter;
	dt_format(TimeBuffer, get_gps_time());
	sprintf(beacon_string, "$$%s,%ld,%s,%08ld,%08ld,%08ld,%08ld,%08ld,%d,%d, %d, %d",
	config.payload_id,
	SentenceCounter++,
	TimeBuffer,
	get_gps_latitude(),
	get_gps_longitude(),
	get_gps_altitude(),
	(get_gps_speed() * 13) / 7,
	get_gps_direction(),
	get_gps_satellites(),
	get_gps_temperature(),
	get_gps_pressure(),
	get_gps_battery());
	
	Count = strlen(beacon_string);

	myCRC = 0xffff;           // Seed
	
	
	for (i = 2; i < Count; i++)
	{   // For speed, repeat calculation instead of looping for each bit
		myCRC ^= (((unsigned int)beacon_string[i]) << 8);
		for (j=0; j<8; j++)
		{
			if (myCRC & 0x8000)
			myCRC = (myCRC << 1) ^ 0x1021;
			else
			myCRC <<= 1;
		}
	}

	beacon_string[Count++] = '*';
	beacon_string[Count++] = Hex((myCRC >> 12) & 15);
	beacon_string[Count++] = Hex((myCRC >> 8) & 15);
	beacon_string[Count++] = Hex((myCRC >> 4) & 15);
	beacon_string[Count++] = Hex(myCRC & 15);
	beacon_string[Count++] = '\n';
	beacon_string[Count++] = '\0';

	beacon_length = strlen( (char *)beacon_string);
	
}

char Hex(unsigned char Character)
{
	char HexTable[] = "0123456789ABCDEF";
	
	return HexTable[Character];
}

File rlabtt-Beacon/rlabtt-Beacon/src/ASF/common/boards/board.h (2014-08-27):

/**
 * \file
 *
 * \brief Standard board header file.
 *
 * This file includes the appropriate board header file according to the
 * defined board (parameter BOARD).
 *
 * Copyright (c) 2009-2014 Atmel Corporation. All rights reserved.
 *
 * \asf_license_start
 *
 * \page License
 *
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
 * 3. The name of Atmel may not be used to endorse or promote products derived
 *    from this software without specific prior written permission.
 *
 * 4. This software may only be redistributed and used in connection with an
 *    Atmel microcontroller product.
 *
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
 * \asf_license_stop
 *
 */

#ifndef _BOARD_H_
#define _BOARD_H_

/**
 * \defgroup group_common_boards Generic board support
 *
 * The generic board support module includes board-specific definitions
 * and function prototypes, such as the board initialization function.
 *
 * \{
 */

#include "compiler.h"

#ifdef __cplusplus
extern "C" {
#endif


/*! \name Base Boards
 */
//! @{
#define EVK1100                     1  //!< AT32UC3A EVK1100 board.
#define EVK1101                     2  //!< AT32UC3B EVK1101 board.
#define UC3C_EK                     3  //!< AT32UC3C UC3C-EK board.
#define EVK1104                     4  //!< AT32UC3A3 EVK1104 board.
#define EVK1105                     5  //!< AT32UC3A EVK1105 board.
#define STK600_RCUC3L0              6  //!< STK600 RCUC3L0 board.
#define UC3L_EK                     7  //!< AT32UC3L-EK board.
#define XPLAIN                      8  //!< ATxmega128A1 Xplain board.
#define STK600_RC064X              10  //!< ATxmega256A3 STK600 board.
#define STK600_RC100X              11  //!< ATxmega128A1 STK600 board.
#define UC3_A3_XPLAINED            13  //!< ATUC3A3 UC3-A3 Xplained board.
#define UC3_L0_XPLAINED            15  //!< ATUC3L0 UC3-L0 Xplained board.
#define STK600_RCUC3D              16  //!< STK600 RCUC3D board.
#define STK600_RCUC3C0             17  //!< STK600 RCUC3C board.
#define XMEGA_B1_XPLAINED          18  //!< ATxmega128B1 Xplained board.
#define XMEGA_A1_XPLAINED          19  //!< ATxmega128A1 Xplain-A1 board.
#define XMEGA_A1U_XPLAINED_PRO     20  //!< ATxmega128A1U XMEGA-A1U Xplained Pro board.
#define STK600_RCUC3L4             21  //!< ATUCL4 STK600 board
#define UC3_L0_XPLAINED_BC         22  //!< ATUC3L0 UC3-L0 Xplained board controller board
#define MEGA1284P_XPLAINED_BC      23  //!< ATmega1284P-Xplained board controller board
#define STK600_RC044X              24  //!< STK600 with RC044X routing card board.
#define STK600_RCUC3B0             25  //!< STK600 RCUC3B0 board.
#define UC3_L0_QT600               26  //!< QT600 UC3L0 MCU board.
#define XMEGA_A3BU_XPLAINED        27  //!< ATxmega256A3BU Xplained board.
#define STK600_RC064X_LCDX         28  //!< XMEGAB3 STK600 RC064X LCDX board.
#define STK600_RC100X_LCDX         29  //!< XMEGAB1 STK600 RC100X LCDX board.
#define UC3B_BOARD_CONTROLLER      30  //!< AT32UC3B1 board controller for Atmel boards
#define RZ600                      31  //!< AT32UC3A RZ600 MCU board
#define SAM3S_EK                   32  //!< SAM3S-EK board.
#define SAM3U_EK                   33  //!< SAM3U-EK board.
#define SAM3X_EK                   34  //!< SAM3X-EK board.
#define SAM3N_EK                   35  //!< SAM3N-EK board.
#define SAM3S_EK2                  36  //!< SAM3S-EK2 board.
#define SAM4S_EK                   37  //!< SAM4S-EK board.
#define STK600_RCUC3A0             38  //!< STK600 RCUC3A0 board.
#define STK600_MEGA                39  //!< STK600 MEGA board.
#define MEGA_1284P_XPLAINED        40  //!< ATmega1284P Xplained board.
#define SAM4S_XPLAINED             41  //!< SAM4S Xplained board.
#define ATXMEGA128A1_QT600         42  //!< QT600 ATXMEGA128A1 MCU board.
#define ARDUINO_DUE_X              43  //!< Arduino Due/X board.
#define STK600_RCUC3L3             44  //!< ATUCL3 STK600 board
#define SAM4L_EK                   45  //!< SAM4L-EK board.
#define STK600_MEGA_RF             46  //!< STK600 MEGA RF EVK board.
#define XMEGA_C3_XPLAINED          47  //!< ATxmega384C3 Xplained board.
#define STK600_RC032X              48  //!< STK600 with RC032X routing card board.
#define SAM4S_EK2                  49  //!< SAM4S-EK2 board.
#define XMEGA_E5_XPLAINED          50  //!< ATxmega32E5 Xplained board.
#define SAM4E_EK                   51  //!< SAM4E-EK board.
#define ATMEGA256RFR2_XPLAINED_PRO 52  //!< ATmega256RFR2 Xplained Pro board.
#define SAM4S_XPLAINED_PRO         53  //!< SAM4S Xplained Pro board.
#define SAM4L_XPLAINED_PRO         54  //!< SAM4L Xplained Pro board.
#define ATMEGA256RFR2_ZIGBIT       55  //!< ATmega256RFR2 zigbit
#define XMEGA_RF233_ZIGBIT         56  //!< ATxmega256A3U with AT86RF233 Zigbit
#define XMEGA_RF212B_ZIGBIT        57  //!< ATxmega256A3U with AT86RF212B Zigbit
#define SAM4S_WPIR_RD              58  //!< SAM4S-WPIR-RD board.
#define SAMD20_XPLAINED_PRO        59  //!< SAM D20 Xplained Pro board
#define SAM4L8_XPLAINED_PRO        60  //!< SAM4L8 Xplained Pro board.
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

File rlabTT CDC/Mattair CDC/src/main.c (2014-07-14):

/*____________________________________________________________________________*/
/*
 * File: main.c
 *
 * Created: 07/06/2014 16:01:06
 * Revised  14/07/2014 16:55
 * Author: Richard Ibbotson
 * Compiler:    GNU-AVR-GCC
 * Project:  rlab Telemetry Transmitter 
 */
/*____________________________________________________________________________*/
/*
 * 
 *  This source module implements the main functions of the rlab Telemetry
 *  Transmitter
 *
 *
*/
/*____________________________________________________________________________*/
/*
 * Copyright, License and Attribution:
 *
 
 *
 * Copyright (c) 2014 Richard Ibbotson (richard.ibbotson@btinternet.com)
 *
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
 * You should have received a copy of the GNU General Public License
 * along with this program.  If not, see <http://www.gnu.org/licenses/>.
 */
/*____________________________________________________________________________*/


#include <asf.h>
#include "conf_usb.h"
#include  "cmnd.h"
#include "gps.h"
#include "ntx2b.h"
#include "i2c400.h"

#include <avr/pgmspace.h> 

static volatile bool main_b_cdc_enable = false;

// Welcome message

const  char  psWelcome[] PROGMEM = "\nrlab.org.uk : HAB Monitor : Free as in air: ";
/**
 * \brief Timer Counter Overflow interrupt callback function
 *
 * This function is called when an overflow interrupt has occurred on
 * MILLISEC_TIMER .
 */
static void millisec_ovf_interrupt_callback(void)
{
	millisecTimer();
}

bool    b5msecTaskReq;
bool    b50mSecTaskReq;
bool    b500msecTaskReq;
bool	cdcRxChar;
static  unsigned long  ulClockTicks;     // General-purpose "tick" counter


/*! \brief Main function. Execution starts here.
 */
int main(void)
{
	irq_initialize_vectors();
	cpu_irq_enable();

	// Initialize the sleep manager
	sleepmgr_init();
	adc_init();
	dac_init();
	sysclk_init();
	board_init();
	i2c400_init();
	
	LED_Off(LED0_GPIO);
	
	// start the millisecond timer
	tc_enable(&MILLISEC_TIMER);
	tc_set_overflow_interrupt_callback(&MILLISEC_TIMER,
	millisec_ovf_interrupt_callback);
	tc_set_wgm(&MILLISEC_TIMER, TC_WG_NORMAL);
	tc_write_period(&MILLISEC_TIMER, MILLISEC_TIMER_PERIOD); //timer is 1ms
	tc_set_overflow_interrupt_level(&MILLISEC_TIMER, TC_INT_LVL_LO);
	tc_set_resolution(&MILLISEC_TIMER, MILLISEC_TIMER_RESOLUTION); // set the timer resolution to 1us
	
	// Start USB stack to authorize VBus monitoring
	udc_start();
	cdcRxChar = FALSE;
	
	// Start the ADC
	adc_enable(&MY_ADC);
	
	// Start the DAC
	dac_enable(&MY_DAC);
	
	// Start the UARTS
	gps_uart_init();
	usart_tx_enable(GPS_USART_SERIAL);
	usart_rx_enable(GPS_USART_SERIAL);
	ntx2b_uart_init();
	ext_uart_init();
	usart_tx_enable(EXT_USART_SERIAL);
	usart_rx_enable(EXT_USART_SERIAL);
	se95_init();
	
	gps_init();
	
	// The main loop 
	
	while (true) {
		if(cdcRxChar){
			while(udi_cdc_is_rx_ready()){
				 hci_process_input( udi_cdc_getc());
				 
			}				 
			cdcRxChar = FALSE;
		}
		get_gps_data();
		sleepmgr_enter_sleep();
	}
}

void main_suspend_action(void)
{
	
}

void main_resume_action(void)
{
	
}

void main_sof_action(void)
{
	if (!main_b_cdc_enable)
		return;
	
}

bool main_cdc_enable(uint8_t port)
{
	main_b_cdc_enable = true;
	// Open communication
	return true;
}

void main_cdc_disable(uint8_t port)
{
	main_b_cdc_enable = false;
	// Close communication
}

void main_cdc_set_dtr(uint8_t port, bool b_enable)
{
	if (b_enable) {
		// Host terminal has open COM
		// Startup message to CDC Port
		cdcPutstr_P( psWelcome );      // output msg to serial port
		hci_put_resp_term();        // prompt
		hci_clear_command();
	}else{
		// Host terminal has close COM
		
	}
}

void main_cdc_rx_notify(uint8_t port)
{
	cdcRxChar = TRUE;
}


void adc_init(void)
{    struct adc_config adc_conf;
	 struct adc_channel_config adcch_conf; 
	    
	 adc_read_configuration(&MY_ADC, &adc_conf);    	  
	 adc_set_conversion_parameters(&adc_conf, ADC_SIGN_OFF, ADC_RES_12,ADC_REF_BANDGAP);    
	 adc_set_conversion_trigger(&adc_conf, ADC_TRIG_FREERUN_SWEEP, 2, 0);    
	 adc_set_clock_rate(&adc_conf, 200000UL);    	  
	 adc_write_configuration(&MY_ADC, &adc_conf); 
	 
	 adcch_read_configuration(&MY_ADC,VBATT_ADC_CH, &adcch_conf); 
	 adcch_set_input(&adcch_conf, ADCCH_POS_PIN0, ADCCH_NEG_NONE, 1);   
	 adcch_write_configuration(&MY_ADC, VBATT_ADC_CH, &adcch_conf);
	 
	 adcch_read_configuration(&MY_ADC,VUSB_ADC_CH, &adcch_conf); 
	 adcch_set_input(&adcch_conf, ADCCH_POS_PIN1, ADCCH_NEG_NONE, 1);  
	 adcch_write_configuration(&MY_ADC, VUSB_ADC_CH, &adcch_conf);  
}

void dac_init(void){
	 struct dac_config dac_conf;
	 
	 dac_read_configuration(&MY_DAC, &dac_conf);
	 dac_set_conversion_parameters(&dac_conf, DAC_REF_BANDGAP, DAC_ADJ_RIGHT);
	 dac_set_active_channel(&dac_conf, NTX2B_DAC, 0);
	 dac_set_conversion_trigger(&dac_conf, 0, 0);
	 dac_write_configuration(&MY_DAC, &dac_conf);
	 
}

void gps_uart_init(void)
{
	static usart_rs232_options_t GPS_USART_SERIAL_OPTIONS = {
		.baudrate = GPS_USART_SERIAL_BAUDRATE,
		.charlength = GPS_USART_SERIAL_CHAR_LENGTH,
		.paritytype = GPS_USART_SERIAL_PARITY,
		.stopbits = GPS_USART_SERIAL_STOP_BIT
	};
	sysclk_enable_module(SYSCLK_PORT_C, PR_USART0_bm);
	usart_init_rs232(GPS_USART_SERIAL, &GPS_USART_SERIAL_OPTIONS);
}



void ext_uart_init(void)
{
	static usart_rs232_options_t EXT_USART_SERIAL_OPTIONS = {
		.baudrate = EXT_USART_SERIAL_BAUDRATE,
		.charlength = EXT_USART_SERIAL_CHAR_LENGTH,
		.paritytype = EXT_USART_SERIAL_PARITY,
		.stopbits = EXT_USART_SERIAL_STOP_BIT
	};
	sysclk_enable_module(SYSCLK_PORT_E, PR_USART0_bm);
	usart_init_rs232(EXT_USART_SERIAL, &EXT_USART_SERIAL_OPTIONS);
}


/*
|   TIMER CALLBACK ---
|   Timer C0.
|   RTI "Tick Handler" / task scheduler.
|   Short time-critical periodic tasks may be called within this ISR;
|   other periodic tasks are scheduled for execution in "background".
|   (See doBackgroundTasks() in main.c)
*/
void millisecTimer(void)
{
	static  char   b500msecTimer = 0;
	static  char   b50mSecTimer = 0;
	static  char   b5mSecTimer = 0;

	ulClockTicks++;

	if ( ++b5mSecTimer >= 5 )
	{
		b5msecTaskReq = 1;
		b5mSecTimer = 0;
		b50mSecTimer++ ;
	}
	if ( b50mSecTimer >= 10 )
	{
		b50mSecTaskReq = 1;
		b50mSecTimer = 0;
		b500msecTimer++ ;
	}
	if ( b500msecTimer >= 10 )
	{
		b500msecTaskReq = 1;
		b500msecTimer = 0;
		LED_Toggle(LED0_GPIO);
		
	}
}

unsigned long main_get_msclock_ticks(void)
{
	return (ulClockTicks);
}

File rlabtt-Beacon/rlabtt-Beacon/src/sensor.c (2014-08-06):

/*____________________________________________________________________________*/
/* File: sensor.c
 *
 * Created: 07/06/2014 16:01:06
 * Revised  02/08/2014 16:55
 * Author: Richard Ibbotson
 * Compiler:    GNU-AVR-GCC
 * Project:  rlab Telemetry Transmitter
 */ 
/*____________________________________________________________________________*/
/*
 * 
 *  This source module implements the sensor for rlab Telemetry Transmitter
 * including the Global Positioning System (GPS) Interface
 *
 *  This module communicates with the ublox Max7q GPS module over an I2C two wire interface
 *  NMEA messages are parsed as received to global parameters for use in telemetry messages.
 *  This module supports the other devices on the I2C bus, temperature and pressure sensor. 
 *  Also support the Analog to digital converters for battery monitoring
*/
/*____________________________________________________________________________*/
/*
 * Copyright, License and Attribution:
 *
 * This is a derived work and a modified version of the TinyGPS++ Library created by 
 * Mikal Hart (2008-2013)
 *
 * 
 *
 * Copyright (c) 2014 Richard Ibbotson (richard.ibbotson@btinternet.com)
 *
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
 * You should have received a copy of the GNU General Public License
 * along with this program.  If not, see <http://www.gnu.org/licenses/>.
 */
/*____________________________________________________________________________*/

#include "sensor.h"
#include "cmnd.h"
#include "timer.h"


#define GPRMC_TERM   "GPRMC"
#define GPGGA_TERM   "GPGGA"

enum {GPS_NO_SAT, GPS_1D, GPS_3D};

//Storage for Parsed GPS Information

struct TGPS	new_gps_data; // structure to build new GPS data in
struct TGPS valid_gps_data; // pointer to where good GPS data is to be put

unsigned char gps_term[15];
unsigned char gps_term_offset, gps_term_number;

bool gps_checksum_term, gps_data_good;

unsigned long gps_last_time_fix, gps_new_time_fix;
unsigned long gps_last_position_fix, gps_new_position_fix;
unsigned char gps_sentence_type, gps_parity;
unsigned char gpsbuf[GPS_BUFFER_SIZE];
char gps_status = GPS_NO_SAT; // status of GPS data

char power_status = POWER_UNKNOWN; // source of power (unknown, USB, battery, both)

twi_options_t m_options = {		.speed     = I2C400_SPEED,
	.chip      = I2C400_ADDRESS,
	
};

unsigned char i2c_buffer[16];

//Package to initialise SE95 Temperature Sensor
twi_package_t se95_init_package = {
	.addr_length = 0,
	.addr		 = {0x00, 0x00, 0x00},
	.chip        = SE95I2C_ADDRESS,
	.buffer      = (void *) &i2c_buffer[0],
	.length      = 0,
	.no_wait     = false
};

//Package to read SE95 Temperature Sensor
twi_package_t se95_read_package = {
	.addr_length = 1,
	.addr		 = {0x00, 0x00, 0x00},
	.chip        = SE95I2C_ADDRESS,
	.buffer      = (void *) &i2c_buffer[0],
	.length      = 2,
	.no_wait     = false
};

//Package to make MPL115 do conversion
twi_package_t mpl115_convert_package = {
	.addr_length = 0,
	.addr		 = {0x00, 0x00, 0x00},
	.chip        = MPL115I2C_ADDRESS,
	.buffer      = (void *) &i2c_buffer[0],
	.length      = 2,
	.no_wait     = false
};

//Package to read MPL115
twi_package_t mpl115_read_package = {
	.addr_length = 1,
	.addr		 = {0x00, 0x00, 0x00},
	.chip        = MPL115I2C_ADDRESS,
	.buffer      = (void *) &i2c_buffer[0],
	.length      = 12,
	.no_wait     = false
};

//Package to read GPS bytes available count
twi_package_t getgps_count = {
	.addr_length = 1, 
	.addr		 = {0xfd, 0x00, 0x00},
	.chip        = GPSI2C_ADDRESS, 
	.buffer      = (void *) &gpsbuf[0],
	.length      = 2,
	.no_wait     = false
};

//Package to read GPS data bytes

twi_package_t getgps_data = {
	.addr_length = 1,
	.addr		 = {0xff, 0x00, 0x00},
	.chip        = GPSI2C_ADDRESS,
	.buffer      = (void *) &gpsbuf[0],
	.length      = GPS_BUFFER_SIZE,
	.no_wait     = false
};

//Package to write UBX GPS data bytes

twi_package_t send_ubx = {
	.addr_length = 0,
	.addr		 = {0x00, 0x00, 0x00},
	.chip        = GPSI2C_ADDRESS,
	.buffer      = (void *) NULL,
	.length      = 0,
	.no_wait     = false
};

void adc_init(void)
{    struct adc_config adc_conf;
	struct adc_channel_config adcch_conf;
	
	adc_read_configuration(&MY_ADC, &adc_conf);
	adc_set_conversion_parameters(&adc_conf, ADC_SIGN_OFF, ADC_RES_12,ADC_REF_BANDGAP);
	adc_set_conversion_trigger(&adc_conf, ADC_TRIG_FREERUN_SWEEP, 2, 0);
	adc_set_clock_rate(&adc_conf, 200000UL);
	adc_write_configuration(&MY_ADC, &adc_conf);
	
	adcch_read_configuration(&MY_ADC,VBATT_ADC_CH, &adcch_conf);
	adcch_set_input(&adcch_conf, ADCCH_POS_PIN0, ADCCH_NEG_NONE, 1);
	adcch_write_configuration(&MY_ADC, VBATT_ADC_CH, &adcch_conf);
	
	adcch_read_configuration(&MY_ADC,VUSB_ADC_CH, &adcch_conf);
	adcch_set_input(&adcch_conf, ADCCH_POS_PIN1, ADCCH_NEG_NONE, 1);
	adcch_write_configuration(&MY_ADC, VUSB_ADC_CH, &adcch_conf);
}

void check_power_source(void)
{
	
	// check what is the power source
	if (adc_get_result(&MY_ADC, VBATT_ADC_CH) > POWER_OK_VOLTS)
	{
		if (adc_get_result(&MY_ADC, VUSB_ADC_CH) > POWER_OK_VOLTS) power_status = POWER_BOTH;
		power_status = POWER_BATTERY;
	}
	else if (adc_get_result(&MY_ADC, VUSB_ADC_CH) > POWER_OK_VOLTS) power_status = POWER_USB;
	else power_status = POWER_UNKNOWN;
}

void sensor_init(void)
{
	// start the ADC
	adc_init();
	
	// Initialise the I2C bus
	i2c400_init();
	
	// Initialise the valid  GPS structure
	
	valid_gps_data.Time = 0;
	valid_gps_data.Date = 0;
	valid_gps_data.Latitude = 0;
	valid_gps_data.Longitude = 0;
	valid_gps_data.Altitude = 0;
	valid_gps_data.Speed = 0;
	valid_gps_data.Direction = 0;
	valid_gps_data.Satellites = 0;
	valid_gps_data.Temperature = 0;
	valid_gps_data.Pressure = 0;
	valid_gps_data.Battery = 0;
	
	// Send our GPS Flight mode string
	SetFlightMode();
	
	// Initialise other I2C devices
	se95_init();	// Thermometer
}
	
void SendUBX(unsigned char *MSG, int len)
{
	send_ubx.buffer = MSG;
	send_ubx.length = len;
	
	twi_master_write(&TWI_I2C400, &send_ubx);
}

void SetFlightMode(void)
{
	// Send navigation configuration command
	unsigned char setNav[] = {0xB5, 0x62, 0x06, 0x24, 0x24, 0x00, 0xFF, 0xFF, 0x06, 0x03, 0x00, 0x00, 0x00, 0x00, 0x10, 0x27, 0x00, 0x00, 0x05, 0x00, 0xFA, 0x00, 0xFA, 0x00, 0x64, 0x00, 0x2C, 0x01, 0x00, 0x00, 0x00, 0x00, 0x00, 0x00, 0x00, 0x00, 0x00, 0x00, 0x00, 0x00, 0x00, 0x00, 0x16, 0xDC};
	SendUBX(setNav, sizeof(setNav));
}
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

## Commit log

2014-07-01 rlab Telemetry Transceiver Development Board
    ATXMega128A4U Development board for High Altitude Balloon Telemetry
    Transmitter using NTX2B 434MHz transmitter and Ublox7Q GPS
2014-07-01 First Post of Battery Board
    Battery Holder with boost regulator
    [BatteryPower.brd, BatteryPower.sch]
2014-07-01 First Post for XMega Development Board
    ATXMega128A4U Telemetry Transmitter Board with NTX2B 434MHz transmitter
    and ublox7Q GPS
    [rlabTT.brd, rlabTT.sch]
2014-07-01 DFU Bootloader for rlab Telemetry Transmitter board
    Modified bootloader for rlab Telemetry Transmitter to use pin PD2 as the
    boot enable input.
2014-07-01 Modified conf.isp.h file to use the input PD2 for boot
    Conf.isp.h file is modified to use a different pin on the rlab Telemetry
    Transmitter board.
    Source for bootloader is available from Atmel and built using the IAR
    workbench.
    Hex file is downloader to ATXMega using PDI programmer. ATXMega128A4U
    devices are supplied by Atmel with no bootloader present.
2014-07-01 Add PDFs of schematics
2014-07-01 Add PDF of schematic
2014-07-14 Add First submission of rlabTT CDC
    Submission of development software for rlab Telemetry Transmitter board
2014-08-19 PCB for Superman tracker and batteries
    Smaller boards to go inside body cavity of model
    [BatBoostAAA.brd, BatBoostAAA.sch, PanBatBoostAAA.brd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]
2014-08-27 Add Port selection at start up
    Add code to determine if USB or external serial is used at start up,
    based on configuration and power source

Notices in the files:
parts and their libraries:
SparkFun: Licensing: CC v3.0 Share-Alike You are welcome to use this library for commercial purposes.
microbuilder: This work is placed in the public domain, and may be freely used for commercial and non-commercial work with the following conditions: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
